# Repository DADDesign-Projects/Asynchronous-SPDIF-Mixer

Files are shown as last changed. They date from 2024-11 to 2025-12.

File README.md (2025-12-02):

# Asynchronous S/PDIF Mixer

"Asynchronous SPDIF Mixer" is a hardware and software project designed to synchronize and mix up to three asynchronous S/PDIF streams into a single 48 kHz output stream.  
The system compensates for drift between sources and uses interpolation to ensure smooth and artifact-free audio transitions.  
The project includes USB-MIDI control, allowing real-time mixing of the three audio channels via an external MIDI controller or any MIDI-compatible software.
  
The software, developed in C++ with CubeIDE, is optimized for real-time audio processing and runs on an STM32H743 microcontroller.  
A custom electronic board, designed with KiCad, provides a dedicated hardware platform for this solution.  
  
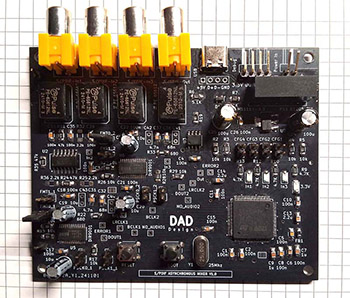
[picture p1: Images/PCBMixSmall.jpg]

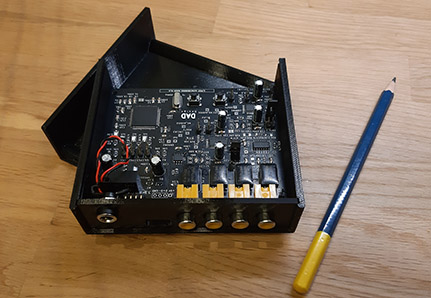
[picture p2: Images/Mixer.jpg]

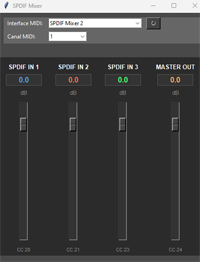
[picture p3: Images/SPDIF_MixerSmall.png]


## 📋 New Evolutions

Recent updates to the project include:

- 🔄 **Enhanced Drift Compensation**: A new algorithm has been implemented for compensating drifts in the input frequencies, ensuring more precise synchronization across streams.
- 🎛️ **Advanced Mixing Controls**: Mixing between the three inputs can now be adjusted in real-time via MIDI over USB, complemented by a Python-based control panel for intuitive configuration. Mix settings are automatically saved and recalled as presets stored directly in flash memory for persistent, non-volatile access.

## 👤 Author

This project is developed by **DAD Design**.

## 📄 License

This project is licensed under the [MIT License](LICENSE).

## ✨ Features

- **Synchronization of Asynchronous S/PDIF Streams:** The project synchronizes three input audio streams, each potentially running at different sample rates ( 48kHz, 44.1kHz, 32kHz), into a unified output stream at 48kHz.
- **Clock Drift Compensation:** Drift between the input streams is handled through periodic drift factor recalculation, ensuring the output remains smooth and synchronized.
- 🎛️ **Real-Time Mixing Controls**: Adjustable mixing levels for the three inputs via any USB-MIDI interface. A Python control panel included as an example for easy configuration.
- 💾 **Preset Memorization**: Mix settings are automatically saved and can be recalled as presets stored in flash memory for quick, persistent access.

## 🛠️ Hardware Platform

The KiCAD folder contains the schematics and PCB files for the project's hardware. These files were created using **KiCAD version 9.0**.

## 🔧 Development Environment

The project is developed and compiled using the **CubeIDE** environment provided by STMicroelectronics. CubeIDE is a fully integrated development environment (IDE) that supports STM32 microcontrollers and provides tools for debugging, flashing, and developing embedded systems.

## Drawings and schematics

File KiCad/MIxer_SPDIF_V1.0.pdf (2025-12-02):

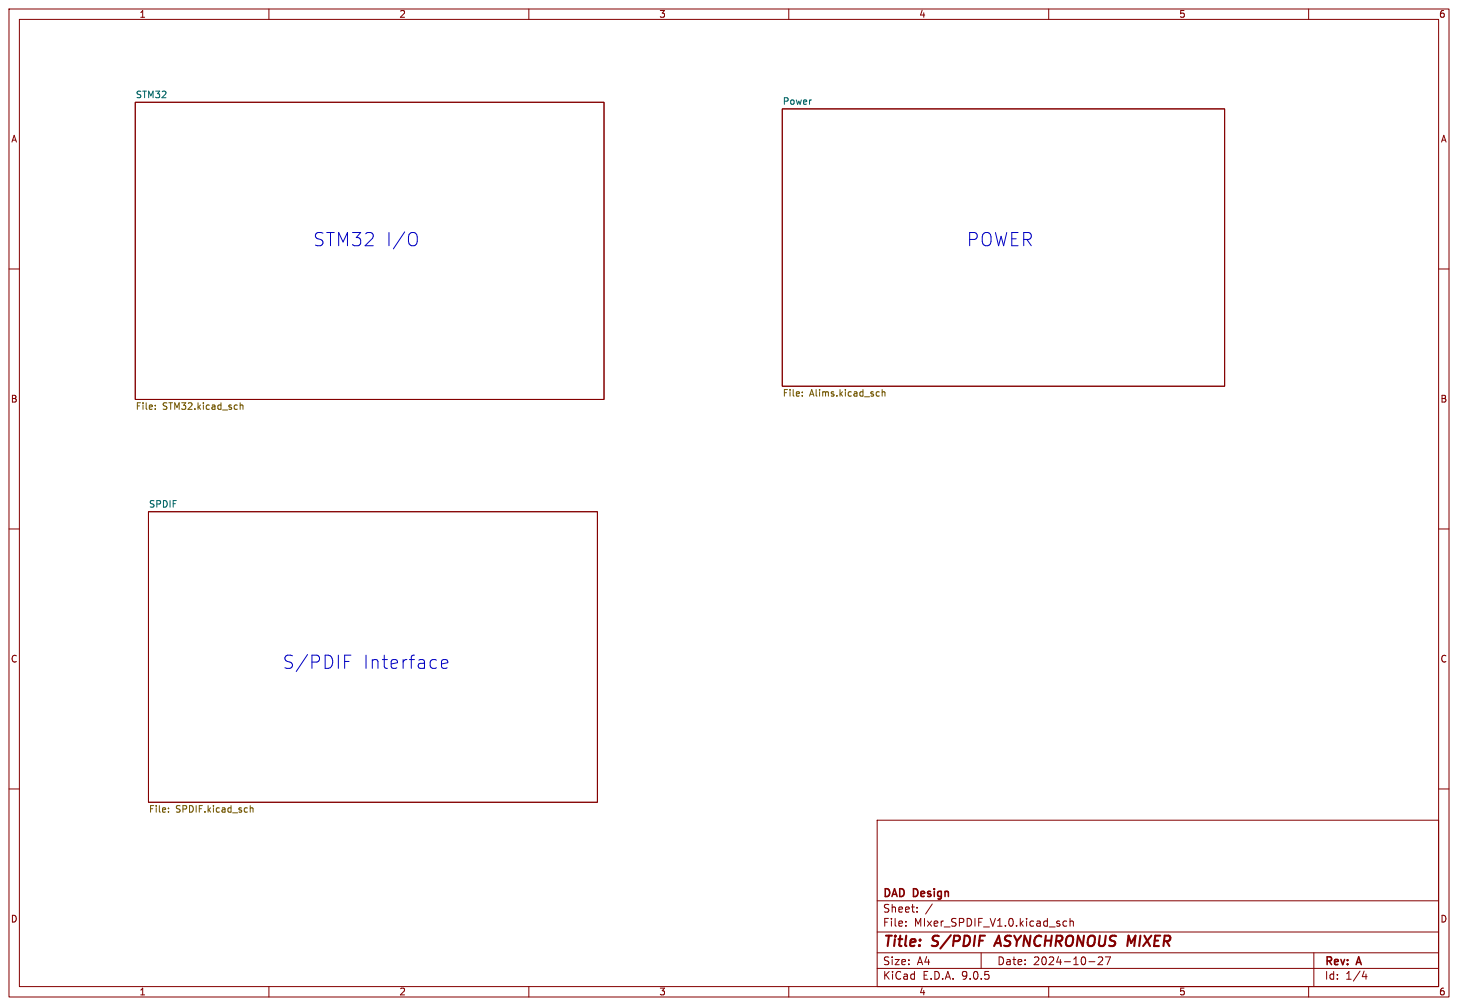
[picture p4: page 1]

Power File: Alims.kicad_sch SPDIF

Id: 1/4 Title: S/PDIF ASYNCHRONOUS MIXER

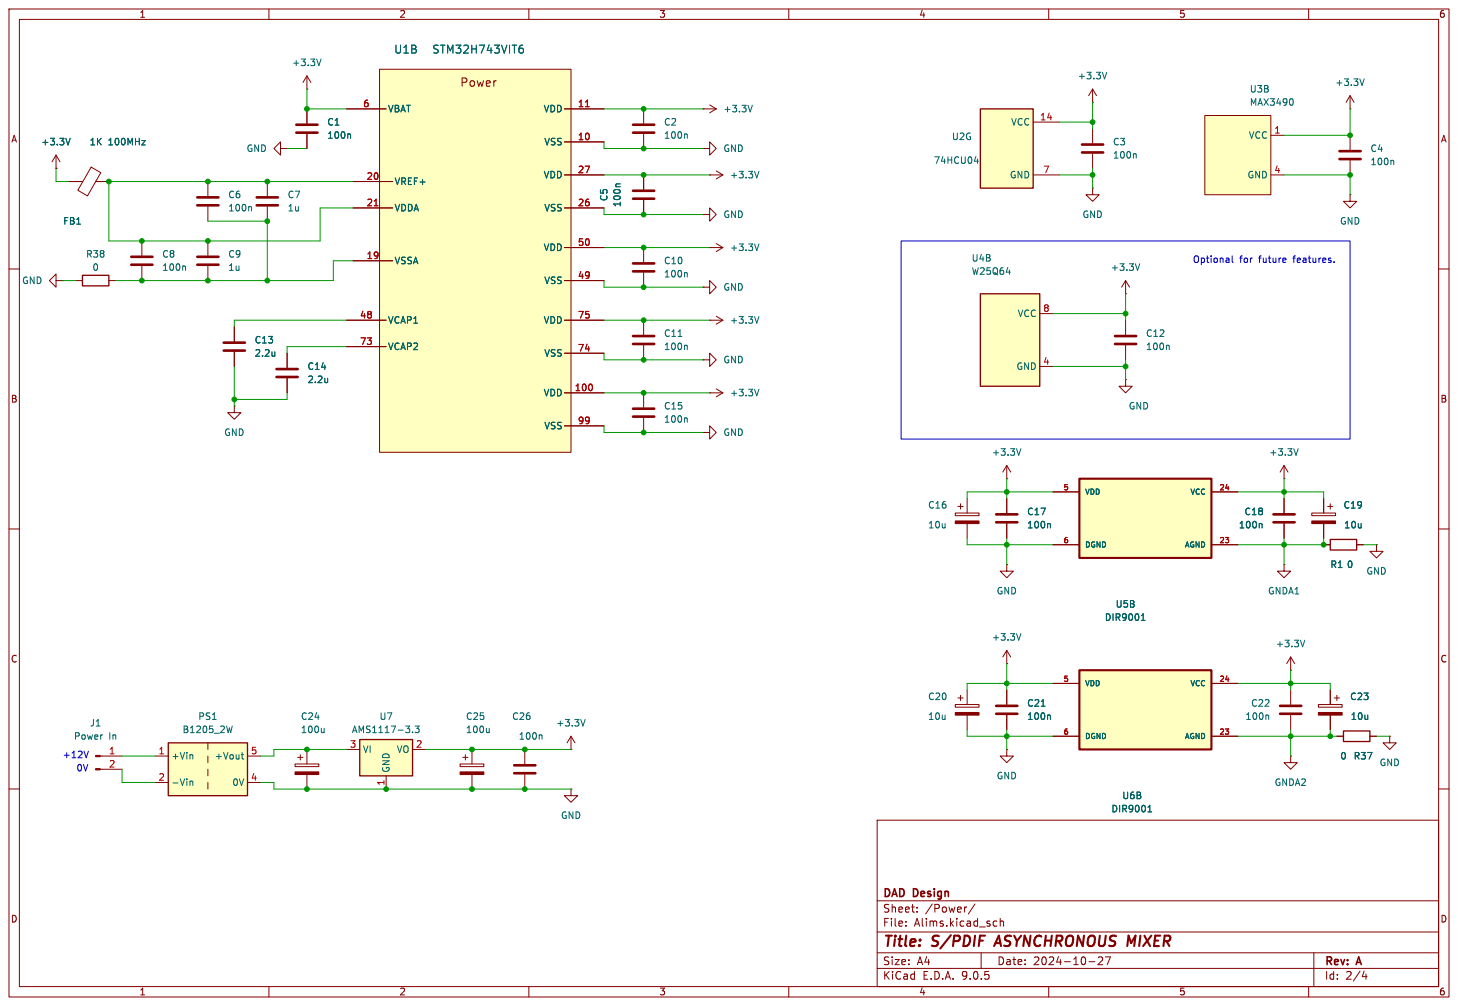
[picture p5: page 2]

Id: 2/4 Title: S/PDIF ASYNCHRONOUS MIXER

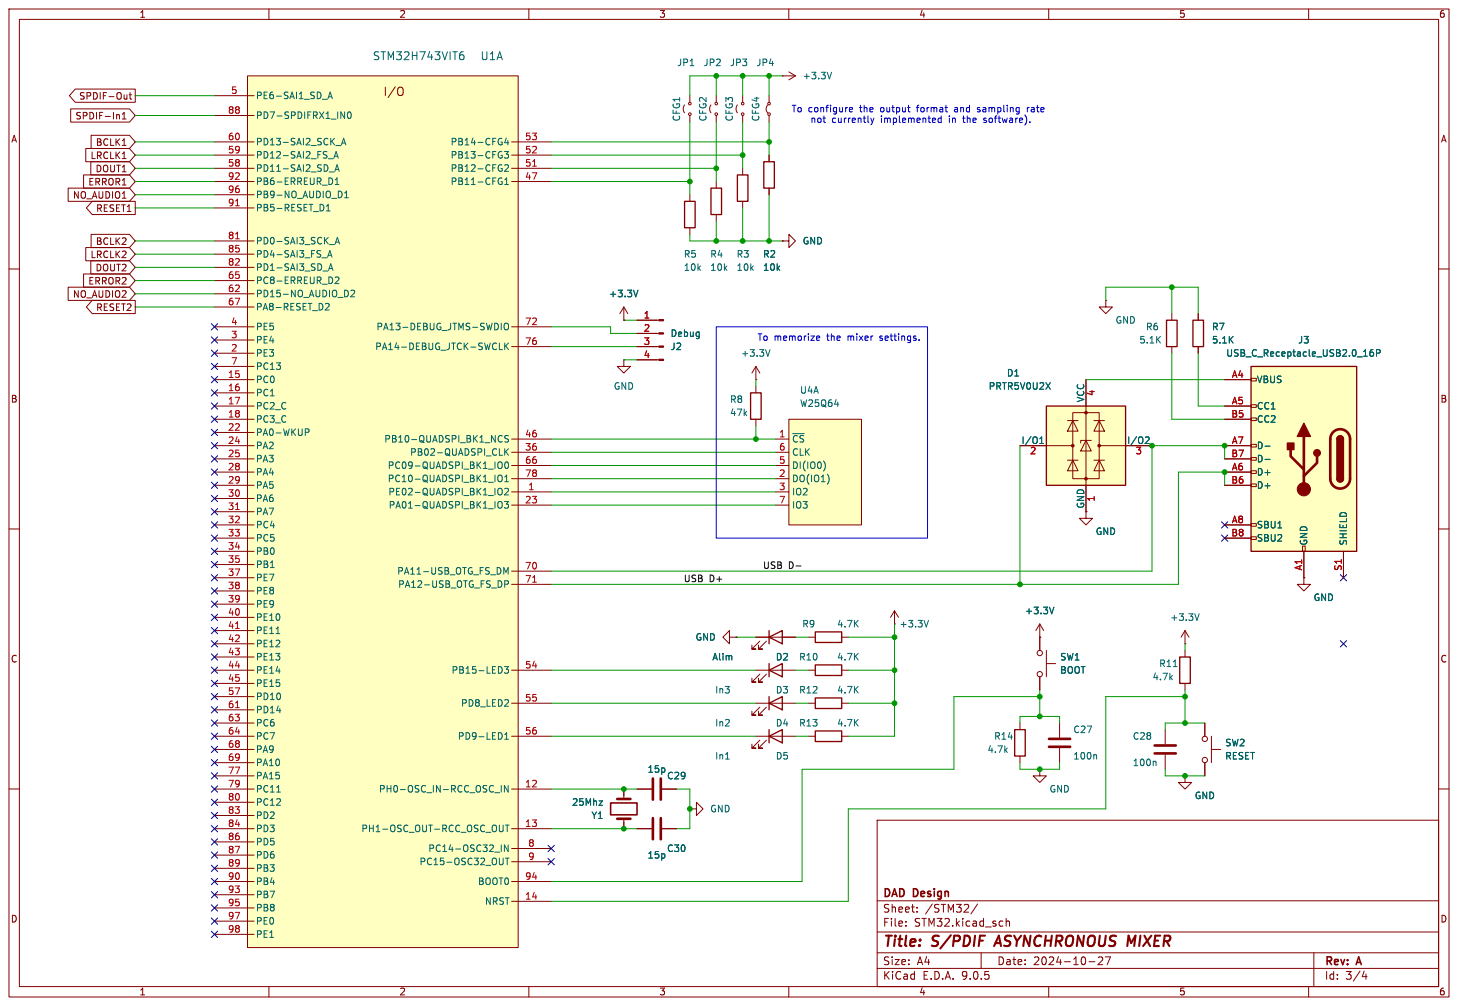
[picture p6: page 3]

~{CS} 1 CLK 6 DI(IO0) 5 DO(IO1) 2

Id: 3/4 Title: S/PDIF ASYNCHRONOUS MIXER

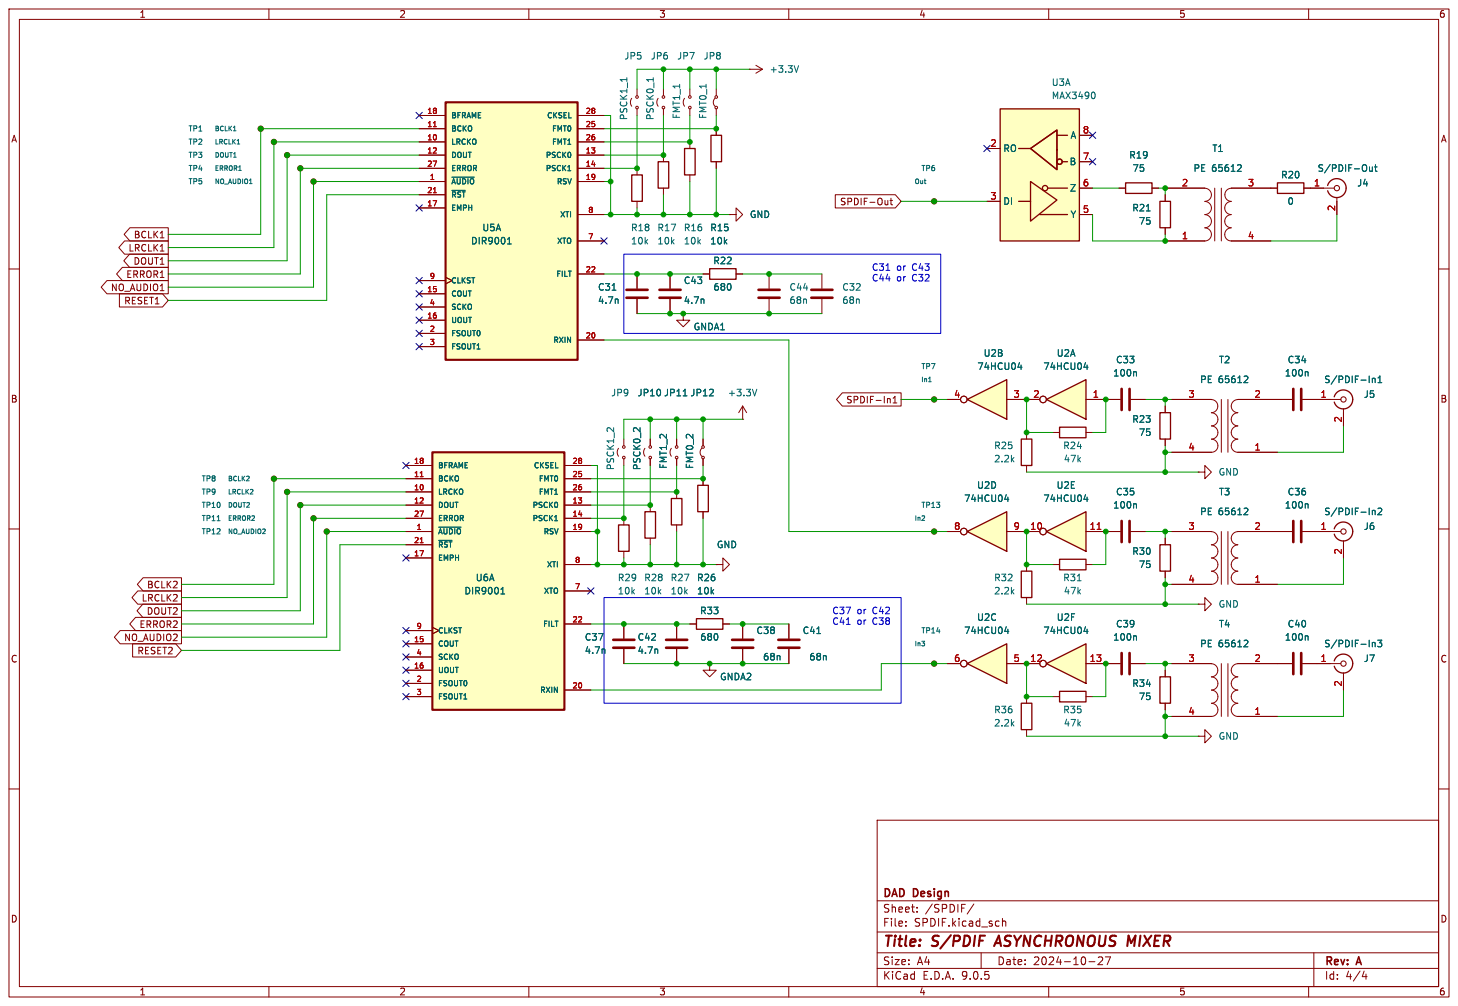
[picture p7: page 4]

Id: 4/4 Title: S/PDIF ASYNCHRONOUS MIXER

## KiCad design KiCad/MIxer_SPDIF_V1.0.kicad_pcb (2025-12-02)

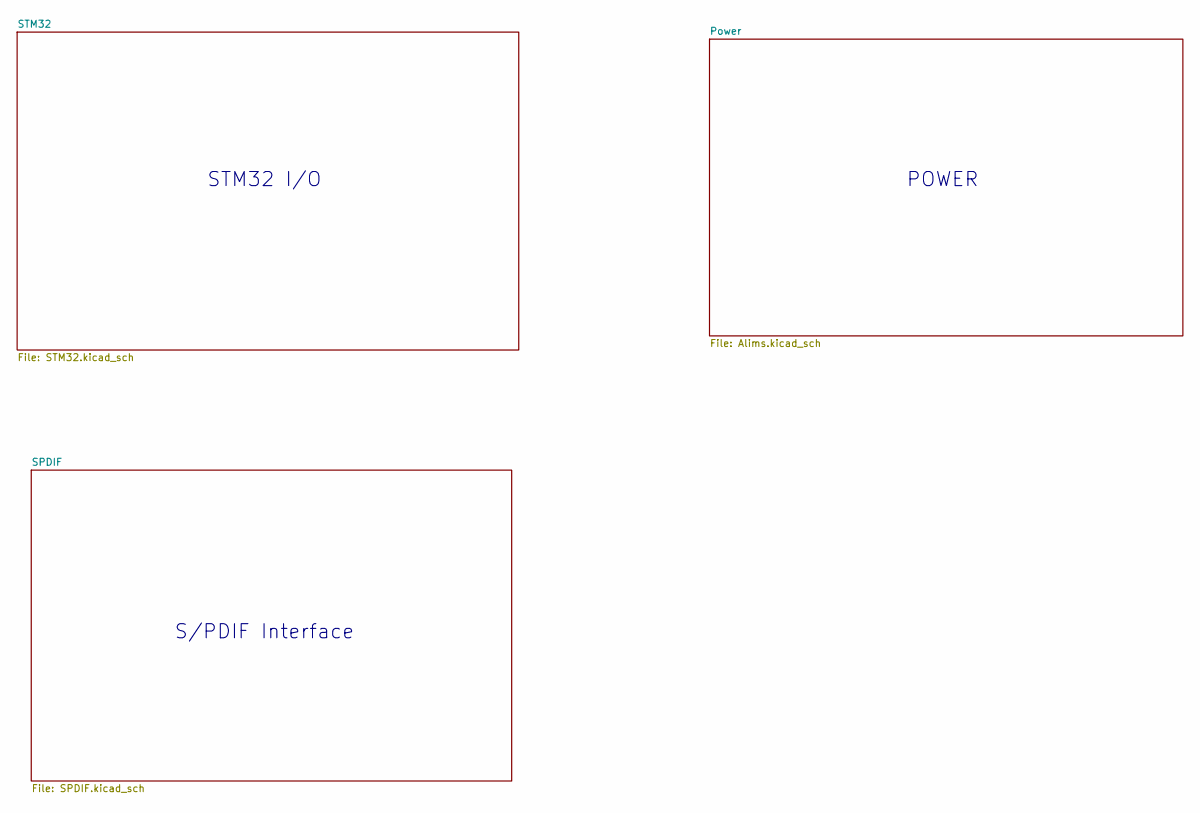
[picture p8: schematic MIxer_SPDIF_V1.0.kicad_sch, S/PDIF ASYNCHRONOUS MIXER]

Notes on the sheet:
POWER
S/PDIF Interface
STM32 I/O

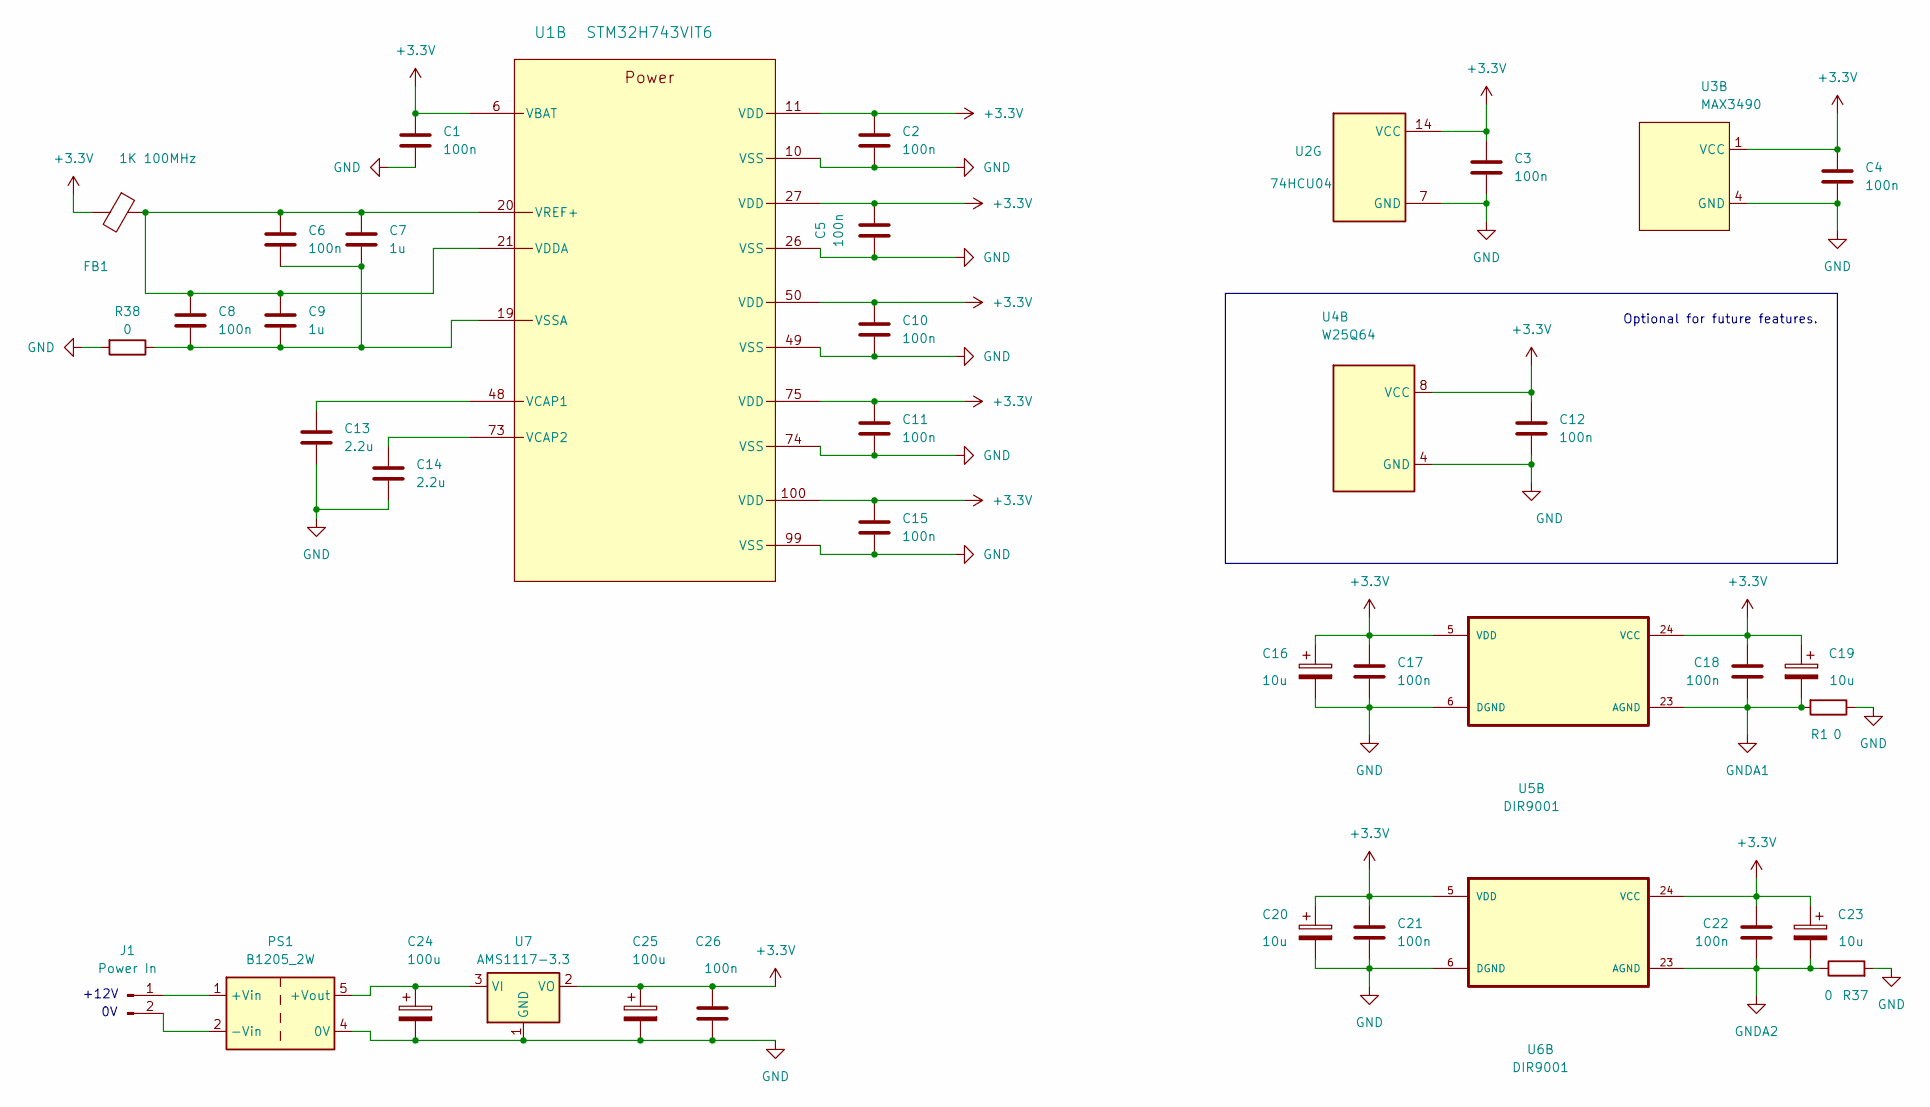
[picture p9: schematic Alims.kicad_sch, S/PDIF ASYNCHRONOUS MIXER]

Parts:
C1, C2, C3, C4, C5, C6, C8, C10, C11, C12, C15, C17, C18, C21, C22, C26: 100n; C_1206_3216Metric_Pad1.33x1.80mm_HandSolder
C7, C9: 1u; C_1206_3216Metric_Pad1.33x1.80mm_HandSolder
C13, C14: 2.2u; C_1206_3216Metric_Pad1.33x1.80mm_HandSolder
C16, C19, C20, C23: 10u; CP_Radial_D5.0mm_P2.50mm
C24, C25: 100u; CP_Radial_D6.3mm_P2.50mm
FB1: 1K 100MHz; C_0805_2012Metric_Pad1.18x1.45mm_HandSolder
J1: Power In; PinHeader_1x02_P2.54mm_Horizontal
PS1: B1205_2W; Converter_DCDC_TRACO_TBA1-xxxxE_Single_THT
R1, R37, R38: 0; SolderJumper-2_P1.3mm_Bridged2Bar_Pad1.0x1.5mm
U1: STM32H743VIT6; LQFP100-14x14mm
U2: 74HCU04; SO-14_5.3x10.2mm_P1.27mm
U3: MAX3490; SOIC-8_3.9x4.9mm_P1.27mm
U4: W25Q64; SOIC-8_5.23x5.23mm_P1.27mm
U5, U6: DIR9001; TSSOP-28-1EP_4.4x9.7mm_P0.65mm_EP2.85x6.7mm
U7: AMS1117-3.3; SOT-223-3_TabPin2

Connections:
+3.3V: C1.1, C2.1, C3.1, C4.1, C5.1, C10.1, C11.1, C12.1, C15.1, C16.1, C17.1, C18.1, C19.1, C20.1, C21.1, C22.1, C23.1, C25.1, C26.1, FB1.2, U1.6 (VBAT), U1.11 (VDD), U1.27 (VDD), U1.50 (VDD), U1.75 (VDD), U1.100 (VDD), U2.14 (VCC), U3.1 (VCC), U4.8 (VCC), U5.5 (VDD), U5.24 (VCC), U6.5 (VDD), U6.24 (VCC), U7.2 (VO); also elsewhere on the board
GND: C1.2, C2.2, C3.2, C4.2, C5.2, C10.2, C11.2, C12.2, C13.2, C14.2, C15.2, C16.2, C17.2, C20.2, C21.2, C24.2, C25.2, C26.2, PS1.4 (0V), R1.1, R37.2, R38.2, U1.10 (VSS), U1.26 (VSS), U1.49 (VSS), U1.74 (VSS), U1.99 (VSS), U2.7 (GND), U3.4 (GND), U4.4 (GND), U5.6 (DGND), U6.6 (DGND), U7.1 (GND); also elsewhere on the board
GNDA1: C18.2, C19.2, R1.2, U5.23 (AGND); also elsewhere on the board
GNDA2: C22.2, C23.2, R37.1, U6.23 (AGND); also elsewhere on the board
unnamed: J1.2 (0V), PS1.2 (-Vin)
unnamed: J1.1 (12V), PS1.1 (+Vin)
unnamed: C24.1, PS1.5 (+Vout), U7.3 (VI)
unnamed: C13.1, U1.48 (VCAP1)
unnamed: C14.1, U1.73 (VCAP2)
unnamed: C6.1, C7.1, C8.1, C9.1, FB1.1, U1.20 (VREF+), U1.21 (VDDA)
unnamed: C6.2, C7.2, C8.2, C9.2, R38.1, U1.19 (VSSA)

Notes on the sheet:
Optional for future features.
+12V

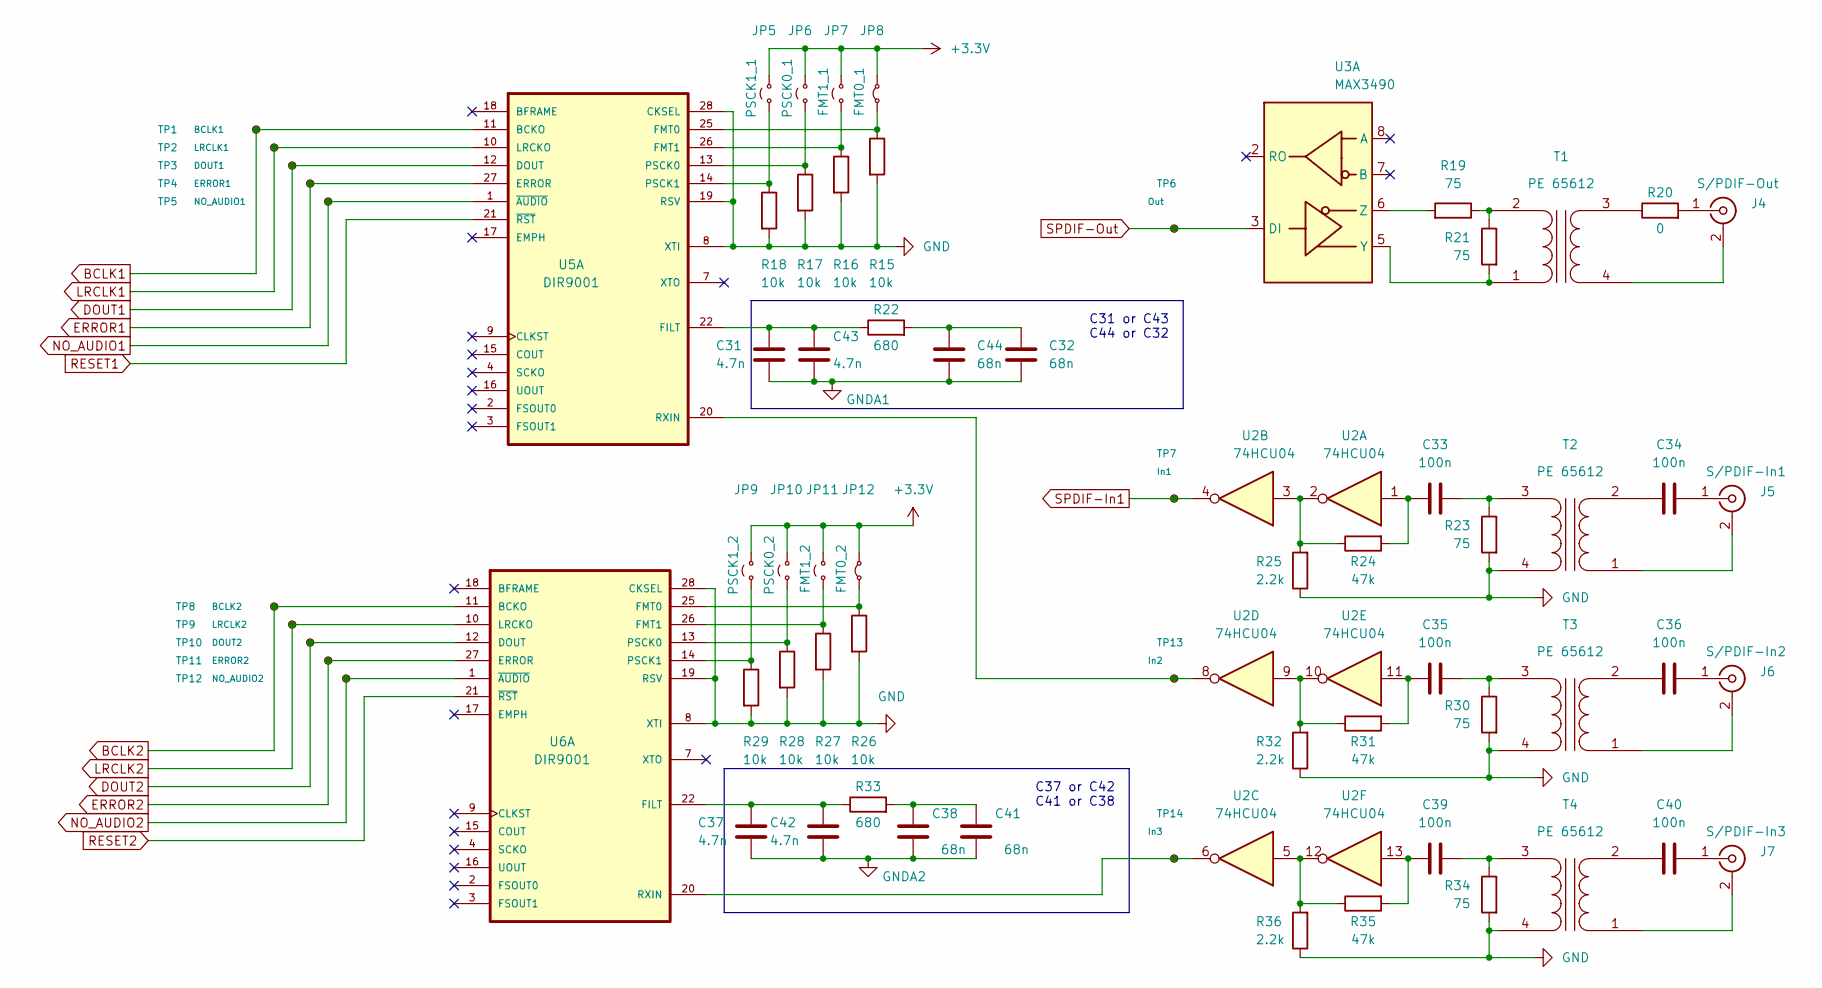
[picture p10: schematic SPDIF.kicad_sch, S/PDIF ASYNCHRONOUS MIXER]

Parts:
C31, C37: 4.7n; C_1206_3216Metric_Pad1.33x1.80mm_HandSolder
C32, C38: 68n; C_1206_3216Metric_Pad1.33x1.80mm_HandSolder
C33, C34, C35, C36, C39, C40: 100n; C_1206_3216Metric_Pad1.33x1.80mm_HandSolder
C41, C44: 68n; C_Rect_L4.6mm_W2.0mm_P2.50mm_MKS02_FKP02
C42, C43: 4.7n; C_Rect_L4.6mm_W2.0mm_P2.50mm_MKS02_FKP02
J4: S/PDIF-Out; CINCH_RCA
J5: S/PDIF-In1; CINCH_RCA
J6: S/PDIF-In2; CINCH_RCA
J7: S/PDIF-In3; CINCH_RCA
JP5: PSCK1_1; PinHeader_1x02_P2.54mm_Vertical
JP6: PSCK0_1; PinHeader_1x02_P2.54mm_Vertical
JP7: FMT1_1; PinHeader_1x02_P2.54mm_Vertical
JP8: FMT0_1; PinHeader_1x02_P2.54mm_Vertical
JP9: PSCK1_2; PinHeader_1x02_P2.54mm_Vertical
JP10: PSCK0_2; PinHeader_1x02_P2.54mm_Vertical
JP11: FMT1_2; PinHeader_1x02_P2.54mm_Vertical
JP12: FMT0_2; PinHeader_1x02_P2.54mm_Vertical
R15, R16, R17, R18, R26, R27, R28, R29: 10k; R_1206_3216Metric_Pad1.30x1.75mm_HandSolder
R19, R21, R23, R30, R34: 75; R_1206_3216Metric_Pad1.30x1.75mm_HandSolder
R20: 0; R_1206_3216Metric_Pad1.30x1.75mm_HandSolder
R22, R33: 680; R_1206_3216Metric_Pad1.30x1.75mm_HandSolder
R24, R31, R35: 47k; R_1206_3216Metric_Pad1.30x1.75mm_HandSolder
R25, R32, R36: 2.2k; R_1206_3216Metric_Pad1.30x1.75mm_HandSolder
T1, T2, T3, T4: PE 65612; PE-65612
TP1: BCLK1; TestPoint_THTPad_1.5x1.5mm_Drill0.7mm
TP2: LRCLK1; TestPoint_THTPad_1.5x1.5mm_Drill0.7mm
TP3: DOUT1; TestPoint_THTPad_1.5x1.5mm_Drill0.7mm
TP4: ERROR1; TestPoint_THTPad_1.5x1.5mm_Drill0.7mm
TP5: NO_AUDIO1; TestPoint_THTPad_1.5x1.5mm_Drill0.7mm
TP6: Out; TestPoint_THTPad_1.5x1.5mm_Drill0.7mm
TP7: In1; TestPoint_THTPad_1.5x1.5mm_Drill0.7mm
TP8: BCLK2; TestPoint_THTPad_1.5x1.5mm_Drill0.7mm
TP9: LRCLK2; TestPoint_THTPad_1.5x1.5mm_Drill0.7mm
TP10: DOUT2; TestPoint_THTPad_1.5x1.5mm_Drill0.7mm
TP11: ERROR2; TestPoint_THTPad_1.5x1.5mm_Drill0.7mm
TP12: NO_AUDIO2; TestPoint_THTPad_1.5x1.5mm_Drill0.7mm
TP13: In2; TestPoint_THTPad_1.5x1.5mm_Drill0.7mm
TP14: In3; TestPoint_THTPad_1.5x1.5mm_Drill0.7mm
U2: 74HCU04; SO-14_5.3x10.2mm_P1.27mm
U3: MAX3490; SOIC-8_3.9x4.9mm_P1.27mm
U5, U6: DIR9001; TSSOP-28-1EP_4.4x9.7mm_P0.65mm_EP2.85x6.7mm

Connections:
+3.3V: JP5.2 (B), JP6.2 (B), JP7.2 (B), JP8.2 (B), JP9.2 (B), JP10.2 (B), JP11.2 (B), JP12.2 (B); also elsewhere on the board
BCLK1: TP1.1, U5.11 (BCKO); also elsewhere on the board
BCLK2: TP8.1, U6.11 (BCKO); also elsewhere on the board
DOUT1: TP3.1, U5.12 (DOUT); also elsewhere on the board
DOUT2: TP10.1, U6.12 (DOUT); also elsewhere on the board
ERROR1: TP4.1, U5.27 (ERROR); also elsewhere on the board
ERROR2: TP11.1, U6.27 (ERROR); also elsewhere on the board
GND: R15.2, R16.2, R17.2, R18.2, R23.2, R25.1, R26.2, R27.2, R28.2, R29.2, R30.2, R32.1, R34.2, R36.1, T2.4 (SB), T3.4 (SB), T4.4 (SB), U5.8 (XTI), U5.19 (RSV), U5.28 (CKSEL), U6.8 (XTI), U6.19 (RSV), U6.28 (CKSEL); also elsewhere on the board
GNDA1: C31.2, C32.2, C43.2, C44.2; also elsewhere on the board
GNDA2: C37.2, C38.2, C41.2, C42.2; also elsewhere on the board
LRCLK1: TP2.1, U5.10 (LRCKO); also elsewhere on the board
LRCLK2: TP9.1, U6.10 (LRCKO); also elsewhere on the board
NO_AUDIO1: TP5.1, U5.1 (~AUDIO); also elsewhere on the board
NO_AUDIO2: TP12.1, U6.1 (~AUDIO); also elsewhere on the board
unnamed: C32.1, C44.1, R22.2
unnamed: C33.1, R24.2, U2.1
unnamed: C35.1, R31.2, U2.11
unnamed: C38.1, C41.1, R33.2
unnamed: C39.1, R35.2, U2.13
unnamed: J4.2 (Ext), T1.4 (SB)
unnamed: J4.1 (In), R20.2
unnamed: J5.2 (Ext), T2.1 (AA)
unnamed: C34.1, J5.1 (In)
unnamed: J6.2 (Ext), T3.1 (AA)
unnamed: C36.1, J6.1 (In)
unnamed: J7.2 (Ext), T4.1 (AA)
unnamed: C40.1, J7.1 (In)
unnamed: JP5.1 (A), R18.1, U5.14 (PSCK1)
unnamed: JP6.1 (A), R17.1, U5.13 (PSCK0)
unnamed: JP7.1 (A), R16.1, U5.26 (FMT1)
unnamed: JP8.1 (A), R15.1, U5.25 (FMT0)
unnamed: JP9.1 (A), R29.1, U6.14 (PSCK1)
unnamed: JP10.1 (A), R28.1, U6.13 (PSCK0)
unnamed: JP11.1 (A), R27.1, U6.26 (FMT1)
unnamed: JP12.1 (A), R26.1, U6.25 (FMT0)
unnamed: R24.1, R25.2, U2.2, U2.3
unnamed: R31.1, R32.2, U2.9, U2.10
unnamed: R35.1, R36.2, U2.5, U2.12
unnamed: R21.2, T1.1 (AA), U3.5 (Y)
unnamed: R19.1, R21.1, T1.2 (AB)
unnamed: R20.1, T1.3 (SA)
unnamed: C34.2, T2.2 (AB)
unnamed: C33.2, R23.1, T2.3 (SA)
unnamed: C36.2, T3.2 (AB)
unnamed: C35.2, R30.1, T3.3 (SA)
unnamed: C40.2, T4.2 (AB)
unnamed: C39.2, R34.1, T4.3 (SA)
unnamed: R19.2, U3.6 (Z)
unnamed: C31.1, C43.1, R22.1, U5.22 (FILT)
unnamed: TP13.1, U2.8, U5.20 (RXIN)
unnamed: C37.1, C42.1, R33.1, U6.22 (FILT)
unnamed: TP14.1, U2.6, U6.20 (RXIN)
RESET1: U5.21 (~RST); also elsewhere on the board
RESET2: U6.21 (~RST); also elsewhere on the board
SPDIF-In1: TP7.1, U2.4; also elsewhere on the board
SPDIF-Out: TP6.1, U3.3 (DI); also elsewhere on the board

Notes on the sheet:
C37 or C42 C41 or C38
C31 or C43 C44 or C32

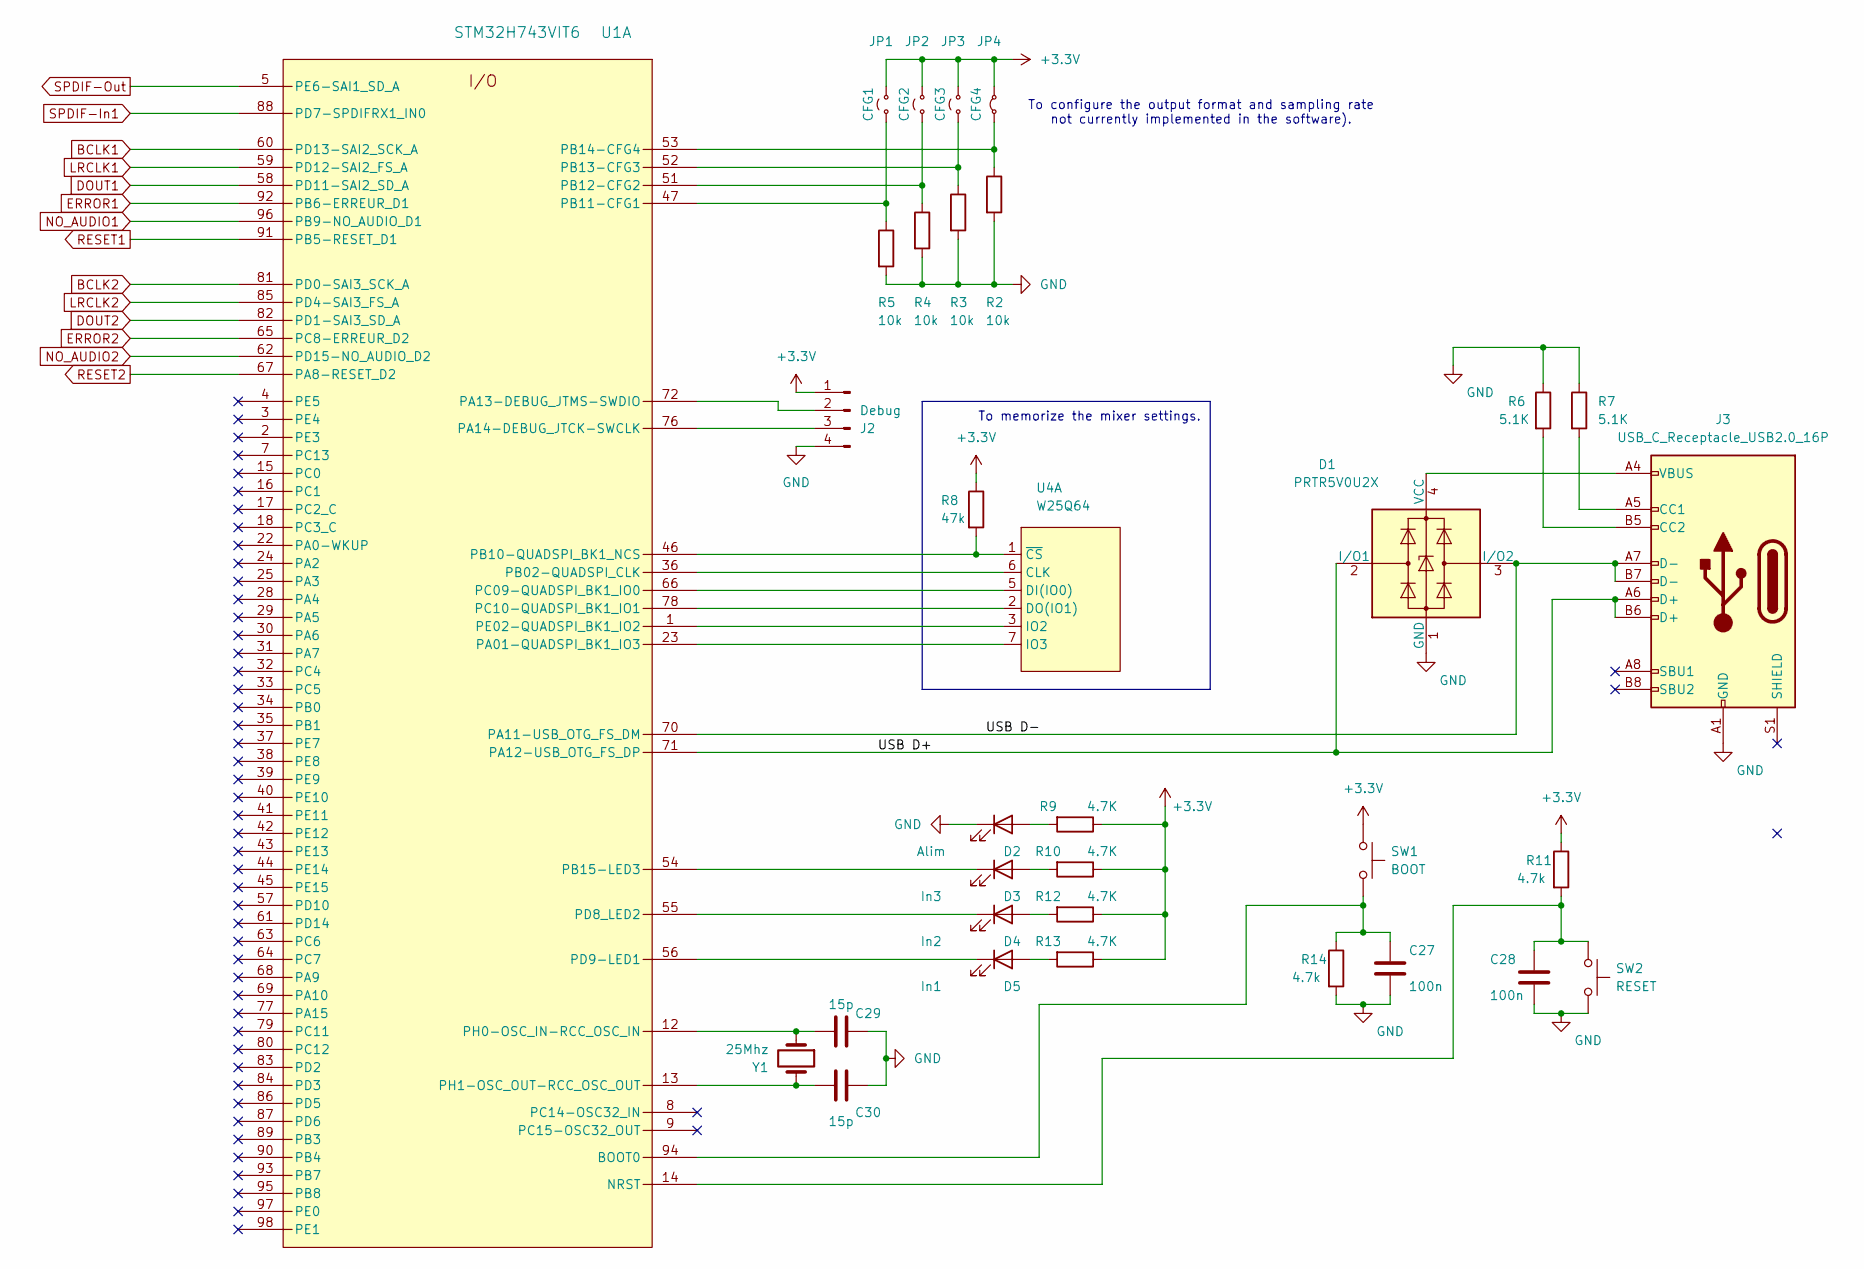
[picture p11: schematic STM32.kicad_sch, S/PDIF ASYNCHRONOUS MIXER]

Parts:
C27, C28: 100n; C_1206_3216Metric_Pad1.33x1.80mm_HandSolder
C29, C30: 15p; C_1206_3216Metric_Pad1.33x1.80mm_HandSolder
D1: PRTR5V0U2X; SOT-143
D2: Alim; LED_1206_3216Metric_Pad1.42x1.75mm_HandSolder
D3: In3; LED_1206_3216Metric_Pad1.42x1.75mm_HandSolder
D4: In2; LED_1206_3216Metric_Pad1.42x1.75mm_HandSolder
D5: In1; LED_1206_3216Metric_Pad1.42x1.75mm_HandSolder
J2: Debug; PinHeader_1x04_P2.54mm_Horizontal
J3: USB_C_Receptacle_USB2.0_16P; USB_C_Receptacle_HCTL_HC-TYPE-C-16P-01A
JP1: CFG1; PinHeader_1x02_P2.54mm_Vertical
JP2: CFG2; PinHeader_1x02_P2.54mm_Vertical
JP3: CFG3; PinHeader_1x02_P2.54mm_Vertical
JP4: CFG4; PinHeader_1x02_P2.54mm_Vertical
R2, R3, R4, R5: 10k; R_1206_3216Metric_Pad1.30x1.75mm_HandSolder
R6, R7: 5.1K; R_1206_3216Metric_Pad1.30x1.75mm_HandSolder
R8: 47k; R_1206_3216Metric_Pad1.30x1.75mm_HandSolder
R9, R10, R12, R13: 4.7K; R_1206_3216Metric_Pad1.30x1.75mm_HandSolder
R11, R14: 4.7k; R_1206_3216Metric_Pad1.30x1.75mm_HandSolder
SW1: BOOT; SW_PUSH_6mm_H5mm
SW2: RESET; SW_PUSH_6mm_H5mm
U1: STM32H743VIT6; LQFP100-14x14mm
U4: W25Q64; SOIC-8_5.23x5.23mm_P1.27mm
Y1: 25Mhz; Quartz

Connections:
+3.3V: J2.1, JP1.2 (B), JP2.2 (B), JP3.2 (B), JP4.2 (B), R8.1, R9.1, R10.1, R11.1, R12.1, R13.1, SW1.1; also elsewhere on the board
/STM32/USB D+: D1.2 (I/O1), J3.A6 (D+), J3.B6 (D+), U1.71 (PA12-USB_OTG_FS_DP)
/STM32/USB D-: D1.3 (I/O2), J3.A7 (D-), J3.B7 (D-), U1.70 (PA11-USB_OTG_FS_DM)
BCLK1: U1.60 (PD13-SAI2_SCK_A); also elsewhere on the board
BCLK2: U1.81 (PD0-SAI3_SCK_A); also elsewhere on the board
DOUT1: U1.58 (PD11-SAI2_SD_A); also elsewhere on the board
DOUT2: U1.82 (PD1-SAI3_SD_A); also elsewhere on the board
ERROR1: U1.92 (PB6-ERREUR_D1); also elsewhere on the board
ERROR2: U1.65 (PC8-ERREUR_D2); also elsewhere on the board
GND: C27.2, C28.2, C29.1, C30.1, D1.1 (GND), D2.1 (K), J2.4, J3.A1 (GND), J3.A12 (GND), J3.B1 (GND), J3.B12 (GND), R2.2, R3.2, R4.2, R5.2, R6.1, R7.1, R14.2, SW2.2; also elsewhere on the board
LRCLK1: U1.59 (PD12-SAI2_FS_A); also elsewhere on the board
LRCLK2: U1.85 (PD4-SAI3_FS_A); also elsewhere on the board
NO_AUDIO1: U1.96 (PB9-NO_AUDIO_D1); also elsewhere on the board
NO_AUDIO2: U1.62 (PD15-NO_AUDIO_D2); also elsewhere on the board
unnamed: D1.4 (VCC), J3.A4 (VBUS), J3.A9 (VBUS), J3.B4 (VBUS), J3.B9 (VBUS)
unnamed: D2.2 (A), R9.2
unnamed: D3.2 (A), R10.2
unnamed: D3.1 (K), U1.54 (PB15-LED3)
unnamed: D4.2 (A), R12.2
unnamed: D4.1 (K), U1.55 (PD8_LED2)
unnamed: D5.2 (A), R13.2
unnamed: D5.1 (K), U1.56 (PD9-LED1)
unnamed: J2.2, U1.72 (PA13-DEBUG_JTMS-SWDIO)
unnamed: J2.3, U1.76 (PA14-DEBUG_JTCK-SWCLK)
unnamed: J3.A5 (CC1), R7.2
unnamed: J3.B5 (CC2), R6.2
unnamed: JP1.1 (A), R5.1, U1.47 (PB11-CFG1)
unnamed: JP2.1 (A), R4.1, U1.51 (PB12-CFG2)
unnamed: JP3.1 (A), R3.1, U1.52 (PB13-CFG3)
unnamed: JP4.1 (A), R2.1, U1.53 (PB14-CFG4)
unnamed: C27.1, R14.1, SW1.2, U1.94 (BOOT0)
unnamed: C28.1, R11.2, SW2.1, U1.14 (NRST)
unnamed: U1.23 (PA01-QUADSPI_BK1_IO3), U4.7 (IO3)
unnamed: U1.36 (PB02-QUADSPI_CLK), U4.6 (CLK)
unnamed: R8.2, U1.46 (PB10-QUADSPI_BK1_NCS), U4.1 (~CS)
unnamed: U1.66 (PC09-QUADSPI_BK1_IO0), U4.5 (DI(IO0))
unnamed: U1.78 (PC10-QUADSPI_BK1_IO1), U4.2 (DO(IO1))
unnamed: U1.1 (PE02-QUADSPI_BK1_IO2), U4.3 (IO2)
unnamed: C29.2, U1.12 (PH0-OSC_IN-RCC_OSC_IN), Y1.1
unnamed: C30.2, U1.13 (PH1-OSC_OUT-RCC_OSC_OUT), Y1.2
RESET1: U1.91 (PB5-RESET_D1); also elsewhere on the board
RESET2: U1.67 (PA8-RESET_D2); also elsewhere on the board
SPDIF-In1: U1.88 (PD7-SPDIFRX1_IN0); also elsewhere on the board
SPDIF-Out: U1.5 (PE6-SAI1_SD_A); also elsewhere on the board

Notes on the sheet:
To configure the output format and sampling rate not currently implemented in the software).
To memorize the mixer settings.

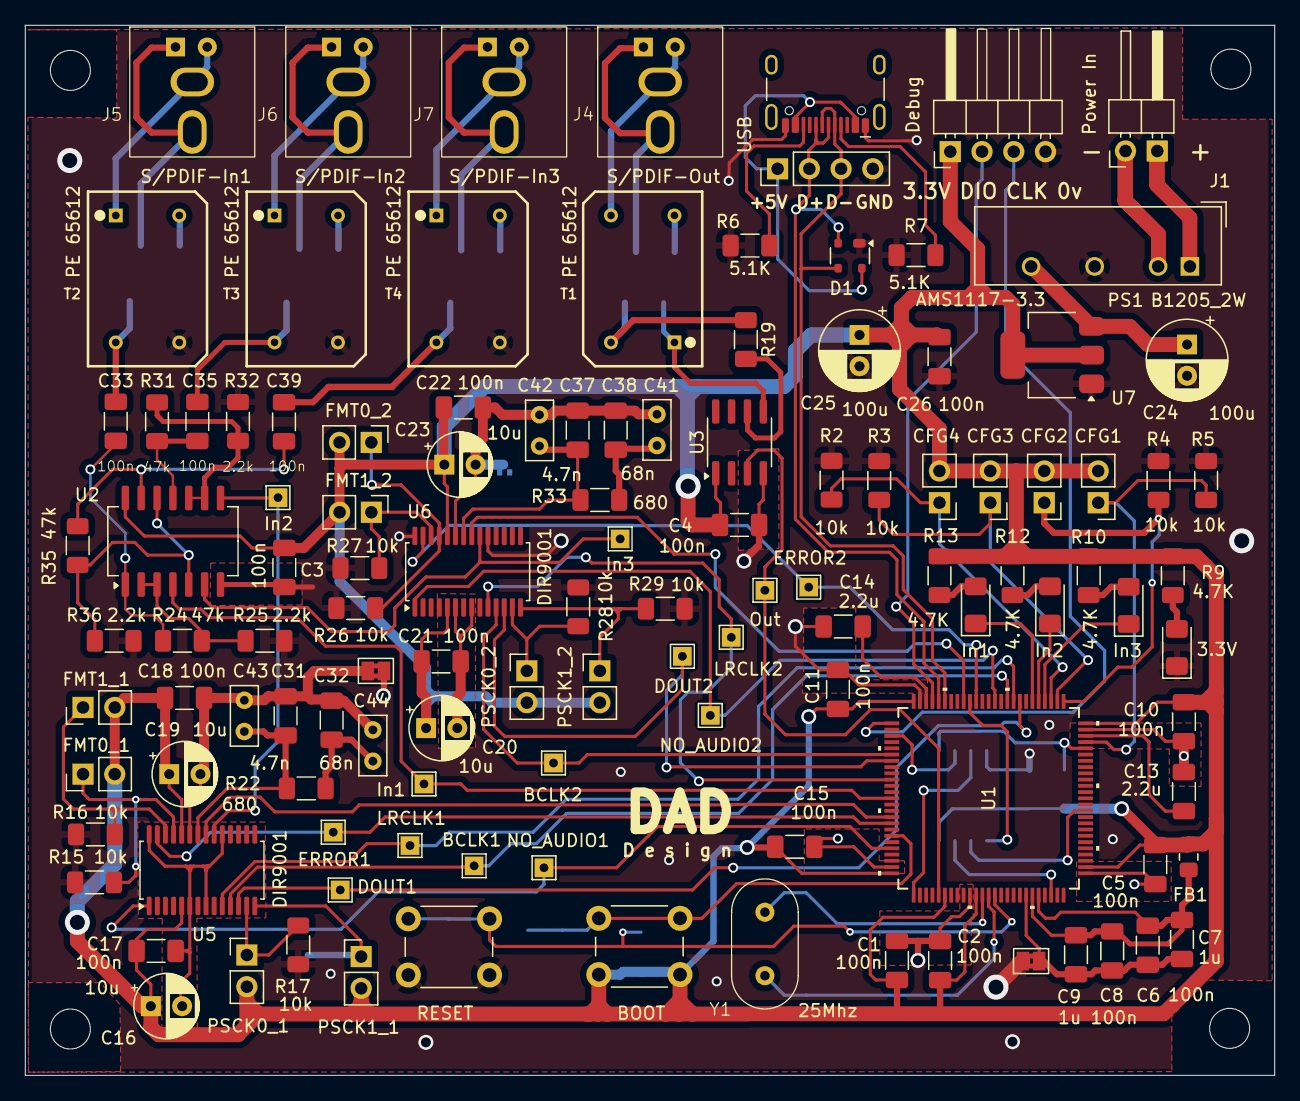
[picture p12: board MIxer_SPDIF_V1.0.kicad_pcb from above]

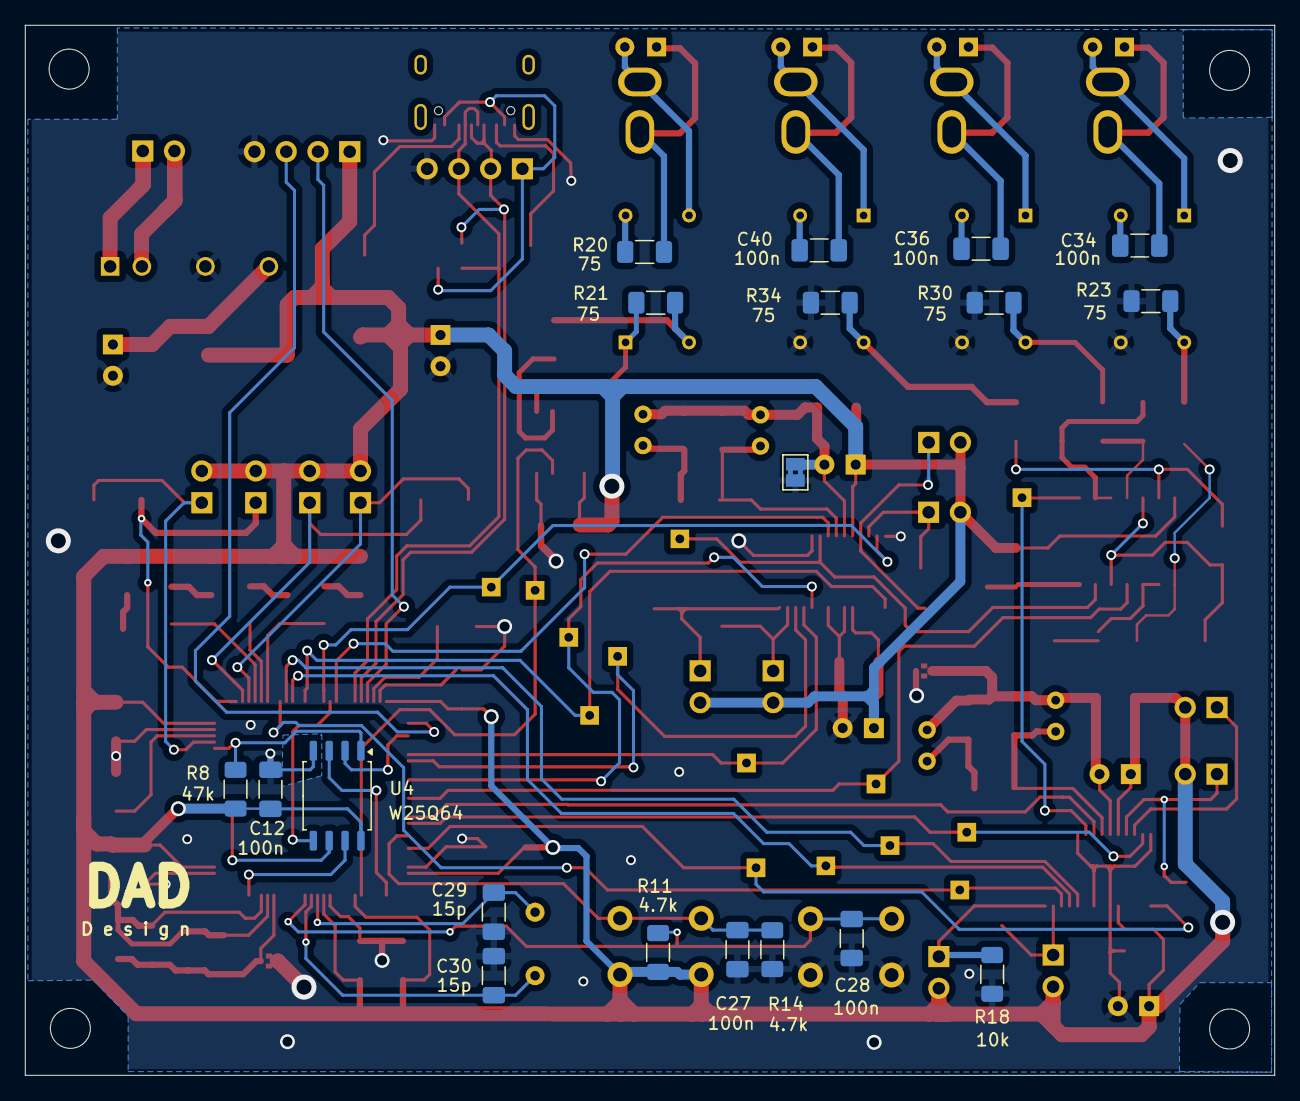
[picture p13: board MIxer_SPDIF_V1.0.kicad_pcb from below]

Board: 2 copper layers, 100.0 x 84.0 mm, 136 parts (19 on the bottom side), 91 nets.

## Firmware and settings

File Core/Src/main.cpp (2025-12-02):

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
/* Includes ------------------------------------------------------------------*/
#include "main.h"
#include "usb_device.h"

/* USER CODE BEGIN Includes */
#include "cMixer.h"
#include "cSAI_SPDIF_TX.h"
#include "cSPDIF_RX.h"
#include "cSAI_DIR9001_RX.h"
#include "usbd_cdc_if.h"
#include "W25Q128.h"
#include "cFlashManager.h"
/* USER CODE END Includes */

/* USER CODE BEGIN PTD */
//#define RAM_D3 __attribute__((section(".RAM_D3_Section")))
/* USER CODE END PTD */


QSPI_HandleTypeDef hqspi;

SAI_HandleTypeDef hsai_BlockA1;
SAI_HandleTypeDef hsai_BlockA2;
SAI_HandleTypeDef hsai_BlockA3;
DMA_HandleTypeDef hdma_sai1_a;
DMA_HandleTypeDef hdma_sai2_a;
DMA_HandleTypeDef hdma_sai3_a;

SPDIFRX_HandleTypeDef hspdif1;
DMA_HandleTypeDef hdma_spdif_rx_dt;

TIM_HandleTypeDef htim6;

/* USER CODE BEGIN PV */
int32_t __SAI_DIR9001_RX1_Buffer[40];
int32_t __SAI_DIR9001_RX2_Buffer[40];

Dad::cMixer 		  	__Mixer;
Dad::cSAI_SPDIF_TX 	  	__SAI_SPDIF_TX;
Dad::cSAI_DIR9001_RX1 	__SAI_DIR9001_RX1;
Dad::cSAI_DIR9001_RX2 	__SAI_DIR9001_RX2;
Dad::cSPDIF_RX 		  	__SPDIFRX;

DadDrivers::cW25Q128		__Flash;
DadDrivers::cFlashManager 	__FlashManager;
bool 						__FlashStatus = false;
MemStruct					__MemStruct;
bool						__MemStructChange = false;

/* USER CODE END PV */

void SystemClock_Config(void);
void PeriphCommonClock_Config(void);
static void MPU_Config(void);
static void MX_GPIO_Init(void);
static void MX_DMA_Init(void);
static void MX_SAI1_Init(void);
static void MX_SAI2_Init(void);
static void MX_SPDIFRX1_Init(void);
static void MX_SAI3_Init(void);
static void MX_QUADSPI_Init(void);
static void MX_TIM6_Init(void);
/* USER CODE BEGIN 0 */
void OnNoteOn(uint8_t channel, uint8_t note, uint8_t velocity){

}
void OnNoteOff(uint8_t channel, uint8_t note, uint8_t velocity){

}

float midiToGain(uint8_t midiValue) {
    if (midiValue == 0) {
        return 0.0f;  // Silence complet
    }

    // Normalisation 0-127 vers 0.0-1.0
    float normalized = midiValue / 127.0f;

    // Mapping linéaire vers la plage -50dB à +6dB (56dB de plage totale)
    float dB = -45.0f + (normalized * 51.0f);

    // Conversion dB vers gain linéaire : gain = 10^(dB/20)
    float gain = powf(10.0f, dB / 20.0f);

    return gain;
}

void OnControlChange(uint8_t channel, uint8_t control, uint8_t value){
	if(control == CC_GAIN_1){
		__MemStruct.vol1 = value;
		__MemStructChange = true;
		float Gain =  midiToGain(value);
		__Mixer.setGain1(Gain);
	}
	if(control == CC_GAIN_2){
		__MemStruct.vol2 = value;
		__MemStructChange = true;
		float Gain =  midiToGain(value);
		__Mixer.setGain2(Gain);
	}
	if(control == CC_GAIN_3){
		__MemStruct.vol3 = value;
		__MemStructChange = true;
		float Gain =  midiToGain(value);
		__Mixer.setGain3(Gain);
	}
	if(control == CC_GAIN_MASTER){
		__MemStruct.volMaster = value;
		__MemStructChange = true;
		float Gain =  midiToGain(value);
		__Mixer.setGainMaster(Gain);
	}
}

void OnProgramChange(uint8_t channel, uint8_t program){

}
/* USER CODE END 0 */

/**
  * @brief  The application entry point.
  * @retval int
  */
int main(void)
{

  /* MPU Configuration--------------------------------------------------------*/
  MPU_Config();

  /* MCU Configuration--------------------------------------------------------*/

  /* Configure The Vector Table address */
  SCB->VTOR = 0x08000000;

  /* Reset of all peripherals, Initializes the Flash interface and the Systick. */
  HAL_Init();

  /* Configure the system clock */
  SystemClock_Config();

  /* Configure the peripherals common clocks */
  PeriphCommonClock_Config();

  /* Initialize all configured peripherals */
  MX_GPIO_Init();
  MX_DMA_Init();
  MX_SAI1_Init();
  MX_SAI2_Init();
  MX_SPDIFRX1_Init();
  MX_SAI3_Init();
  MX_QUADSPI_Init();
  MX_TIM6_Init();
  MX_USB_DEVICE_Init();
  /* USER CODE BEGIN 2 */
  HAL_StatusTypeDef result = __Flash.Init(&hqspi, false, FLASH_ADR);
  __MemStruct.vol1 = 113;
  __MemStruct.vol2 = 113;
  __MemStruct.vol3 = 113;
  __MemStruct.volMaster = 113;
  __Mixer.Initialise();

  if(result == HAL_OK){
	  __FlashStatus = true;
	  __FlashManager.Init(&__Flash, FLASH_ADR);
	  if(false == __FlashManager.Load(&__MemStruct)){
		  __FlashManager.EraseSectors();
		  __FlashManager.Save(__MemStruct);
	  }
	  __Mixer.setGain1(midiToGain(__MemStruct.vol1));
	  __Mixer.setGain2(midiToGain(__MemStruct.vol2));
	  __Mixer.setGain3(midiToGain(__MemStruct.vol3));
	  __Mixer.setGainMaster(midiToGain(__MemStruct.volMaster));
  }

  __SAI_DIR9001_RX1.Init(&hsai_BlockA2, &__Mixer, __SAI_DIR9001_RX1_Buffer);
  __SAI_DIR9001_RX2.Init(&hsai_BlockA3, &__Mixer, __SAI_DIR9001_RX2_Buffer);
  __SPDIFRX.Init(&hspdif1, &htim6, &__Mixer, 25000000);
  __SAI_SPDIF_TX.Init(&hsai_BlockA1, &__Mixer);

  __SAI_DIR9001_RX1.StartReceive();
  __SAI_DIR9001_RX2.StartReceive();
  __SPDIFRX.StartReceive();
  __SAI_SPDIF_TX.StartTransmit();

  uint8_t ctLed = 0;
  uint8_t ctFlash = 0;

  /* USER CODE END 2 */

  /* Infinite loop */
  /* USER CODE BEGIN WHILE */
  while (1)
  {
    /* USER CODE END WHILE */

    /* USER CODE BEGIN 3 */
	  if(__Mixer.GetSampleRate3() != Dad::eSampleRate::NoSync){
		  HAL_GPIO_WritePin(LED3_GPIO_Port, LED3_Pin,  GPIO_PIN_RESET);
	  }else{
		  if(ctLed == 0){
			  HAL_GPIO_WritePin(LED3_GPIO_Port, LED3_Pin,  GPIO_PIN_RESET);
		  }else{
			  HAL_GPIO_WritePin(LED3_GPIO_Port, LED3_Pin,  GPIO_PIN_SET);
		  }
	  }

	  if(__Mixer.GetSampleRate2() != Dad::eSampleRate::NoSync){
		  HAL_GPIO_WritePin(LED1_GPIO_Port, LED1_Pin,  GPIO_PIN_RESET);
	  }else{
		  if(ctLed == 3){
			  HAL_GPIO_WritePin(LED1_GPIO_Port, LED1_Pin,  GPIO_PIN_RESET);
		  }else{
			  HAL_GPIO_WritePin(LED1_GPIO_Port, LED1_Pin,  GPIO_PIN_SET);
		  }
	  }

	  if(__Mixer.GetSampleRate1() != Dad::eSampleRate::NoSync){
		  HAL_GPIO_WritePin(LED2_GPIO_Port, LED2_Pin,  GPIO_PIN_RESET);
	  }else{
		  if(ctLed == 6){
			  HAL_GPIO_WritePin(LED2_GPIO_Port, LED2_Pin,  GPIO_PIN_RESET);
		  }else{
			  HAL_GPIO_WritePin(LED2_GPIO_Port, LED2_Pin,  GPIO_PIN_SET);
		  }
	  }
	  ctLed++;
	  if(ctLed == 9) ctLed=0;

	  ctFlash++;
	  if(ctFlash == 50){
		  ctFlash = 0;
		  if((__FlashStatus == true) && (__MemStructChange == true)){
			  __disable_irq();
			  __MemStructChange = false;
			  __enable_irq();
			  __FlashManager.Save(__MemStruct);
		  }
	  }
	  HAL_Delay(200);
  }
  /* USER CODE END 3 */
}

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
 /* MPU Configuration */

void MPU_Config(void)
{
  MPU_Region_InitTypeDef MPU_InitStruct = {0};

  /* Disables the MPU */
  HAL_MPU_Disable();

  /** Initializes and configures the Region and the memory to be protected
  */
  MPU_InitStruct.Enable = MPU_REGION_ENABLE;
  MPU_InitStruct.Number = MPU_REGION_NUMBER0;
  MPU_InitStruct.BaseAddress = 0x0;
  MPU_InitStruct.Size = MPU_REGION_SIZE_4GB;
  MPU_InitStruct.SubRegionDisable = 0x87;
  MPU_InitStruct.TypeExtField = MPU_TEX_LEVEL0;
  MPU_InitStruct.AccessPermission = MPU_REGION_NO_ACCESS;
  MPU_InitStruct.DisableExec = MPU_INSTRUCTION_ACCESS_DISABLE;
  MPU_InitStruct.IsShareable = MPU_ACCESS_SHAREABLE;
  MPU_InitStruct.IsCacheable = MPU_ACCESS_NOT_CACHEABLE;
  MPU_InitStruct.IsBufferable = MPU_ACCESS_NOT_BUFFERABLE;

  HAL_MPU_ConfigRegion(&MPU_InitStruct);

  /** Initializes and configures the Region and the memory to be protected
  */
  MPU_InitStruct.Number = MPU_REGION_NUMBER1;
  MPU_InitStruct.BaseAddress = 0x08000000;
  MPU_InitStruct.Size = MPU_REGION_SIZE_2MB;
  MPU_InitStruct.SubRegionDisable = 0x0;
  MPU_InitStruct.TypeExtField = MPU_TEX_LEVEL1;
  MPU_InitStruct.AccessPermission = MPU_REGION_PRIV_RO;
  MPU_InitStruct.DisableExec = MPU_INSTRUCTION_ACCESS_ENABLE;
  MPU_InitStruct.IsShareable = MPU_ACCESS_NOT_SHAREABLE;
  MPU_InitStruct.IsCacheable = MPU_ACCESS_CACHEABLE;

  HAL_MPU_ConfigRegion(&MPU_InitStruct);

  /** Initializes and configures the Region and the memory to be protected
  */
  MPU_InitStruct.Number = MPU_REGION_NUMBER2;
  MPU_InitStruct.BaseAddress = 0x90000000;
  MPU_InitStruct.Size = MPU_REGION_SIZE_16MB;
  MPU_InitStruct.AccessPermission = MPU_REGION_PRIV_RO_URO;
  MPU_InitStruct.IsCacheable = MPU_ACCESS_NOT_CACHEABLE;

  HAL_MPU_ConfigRegion(&MPU_InitStruct);
  /* Enables the MPU */
  HAL_MPU_Enable(MPU_PRIVILEGED_DEFAULT);

}

/**
  * @brief  This function is executed in case of error occurrence.
  * @retval None
  */
void Error_Handler(void)
{
  /* USER CODE BEGIN Error_Handler_Debug */
  /* User can add his own implementation to report the HAL error return state */
  __disable_irq();
  while (1)
  {
  }
  /* USER CODE END Error_Handler_Debug */
}
#ifdef USE_FULL_ASSERT
/**
  * @brief  Reports the name of the source file and the source line number
  *         where the assert_param error has occurred.
  * @param  file: pointer to the source file name
  * @param  line: assert_param error line source number
  * @retval None
  */
void assert_failed(uint8_t *file, uint32_t line)
{
  /* USER CODE BEGIN 6 */
  /* User can add his own implementation to report the file name and line number,
     ex: printf("Wrong parameters value: file %s on line %d\r\n", file, line) */
  /* USER CODE END 6 */
}
#endif /* USE_FULL_ASSERT */

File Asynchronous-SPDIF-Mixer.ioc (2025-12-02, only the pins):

Mcu.UserName=STM32H743VITx
PA1.Signal=QUADSPI_BK1_IO3
PA11.Signal=USB_OTG_FS_DM
PA12.Signal=USB_OTG_FS_DP
PA8.GPIO_Label=RESET2
PA8.Signal=GPIO_Output
PB10.Signal=QUADSPI_BK1_NCS
PB12.GPIO_Label=EN_D1
PB12.Signal=GPIO_Input
PB13.GPIO_Label=EN_D2
PB13.Signal=GPIO_Input
PB14.GPIO_Label=EN_D3
PB14.Signal=GPIO_Input
PB15.GPIO_Label=LED3
PB15.Signal=GPIO_Output
PB2.Signal=QUADSPI_CLK
PB5.GPIO_Label=RESET1
PB5.Signal=GPIO_Output
PB6.GPIO_Label=ERROR1
PB6.Signal=GPIO_Input
PB9.GPIO_Label=NO_AUDIO1
PB9.Signal=GPIO_Input
PC10.Signal=QUADSPI_BK1_IO1
PC8.GPIO_Label=ERROR2
PC8.Signal=GPIO_Input
PC9.Signal=QUADSPI_BK1_IO0
PD0.Signal=SAI3_SCK_A
PD1.Signal=SAI3_SD_A
PD11.Signal=SAI2_SD_A
PD12.Signal=SAI2_FS_A
PD13.Signal=SAI2_SCK_A
PD15.GPIO_Label=NO_AUDIO2
PD15.Signal=GPIO_Input
PD4.Signal=SAI3_FS_A
PD7.Signal=SPDIFRX1_IN0
PD8.GPIO_Label=LED2
PD8.Signal=GPIO_Output
PD9.GPIO_Label=LED1
PD9.Signal=GPIO_Output
PE2.Signal=QUADSPI_BK1_IO2
PE6.Signal=SAI1_SD_A

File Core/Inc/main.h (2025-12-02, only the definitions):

#define EN_D1_Pin GPIO_PIN_12
#define EN_D1_GPIO_Port GPIOB
#define EN_D2_Pin GPIO_PIN_13
#define EN_D2_GPIO_Port GPIOB
#define EN_D3_Pin GPIO_PIN_14
#define EN_D3_GPIO_Port GPIOB
#define LED3_Pin GPIO_PIN_15
#define LED3_GPIO_Port GPIOB
#define LED2_Pin GPIO_PIN_8
#define LED2_GPIO_Port GPIOD
#define LED1_Pin GPIO_PIN_9
#define LED1_GPIO_Port GPIOD
#define NO_AUDIO2_Pin GPIO_PIN_15
#define NO_AUDIO2_GPIO_Port GPIOD
#define ERROR2_Pin GPIO_PIN_8
#define ERROR2_GPIO_Port GPIOC
#define RESET2_Pin GPIO_PIN_8
#define RESET2_GPIO_Port GPIOA
#define RESET1_Pin GPIO_PIN_5
#define RESET1_GPIO_Port GPIOB
#define ERROR1_Pin GPIO_PIN_6
#define ERROR1_GPIO_Port GPIOB
#define NO_AUDIO1_Pin GPIO_PIN_9
#define NO_AUDIO1_GPIO_Port GPIOB
#define CC_GAIN_1 21
#define CC_GAIN_2 20
#define CC_GAIN_3 22
#define CC_GAIN_MASTER 23
#define MIDI_CANAL 1
#define FLASH_ADR 0x90000000

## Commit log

2024-10-09 Device Handler Redesign
2024-11-30 Add PCB
    [Alims.kicad_sch, MIxer_SPDIF_V1.0.kicad_pcb, MIxer_SPDIF_V1.0.kicad_sch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]
2024-12-01 minor fixes
    [SPDIF.kicad_sch]
2024-12-04 Adjustment of clocks.
    Adjustment of clocks: Switch to quartz and fine-tuning of the output sampling rate.
2024-12-04 Reduction of the drift correction factor.
    Reduction of the drift correction factor to accommodate less precise devices.
2025-02-05 stupid float conversion bug fix
    [cMixer.h]
2025-12-02 Minor and non-functional changes migration to KiCad 9
    [Alims.kicad_sch, MIxer_SPDIF_V1.0.kicad_pcb, MIxer_SPDIF_V1.0.kicad_sch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]
2025-12-02 Redesign of the drift compensation algorithm; addition of mixing for the 3 SPDIF channels via MIDI over USB.
    [Asynchronous-SPDIF-Mixer.ioc, W25Q128.cpp, cFlashManager.cpp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]

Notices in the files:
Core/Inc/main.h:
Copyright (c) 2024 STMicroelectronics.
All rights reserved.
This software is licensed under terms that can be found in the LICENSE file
